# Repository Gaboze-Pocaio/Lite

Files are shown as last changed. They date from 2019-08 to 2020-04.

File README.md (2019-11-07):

# Gaboze Lite Edition
Gaboze Lite is an even more no frills version of the Game Boy Pocket and Raspberry Pi Zero.

## What Did We Do?

* [x] Lakka Only Release *(You Can Still Have RetroPie)*
* [x] TP4056 Module Removed for more efficient Texs Instruments
* [x] 5V Power Rail
* [x] Full USB OTG Support
* [x] New Button Library With Better Actuation
* [x] Two Buttons Only

## Why Did We Do This

Well, we slimmed it down to a two button build (you can always wire more on your own). After market evaluation, and to keep costs lower.

## Preview

| Top  | Bottom |
| ---- | --- |
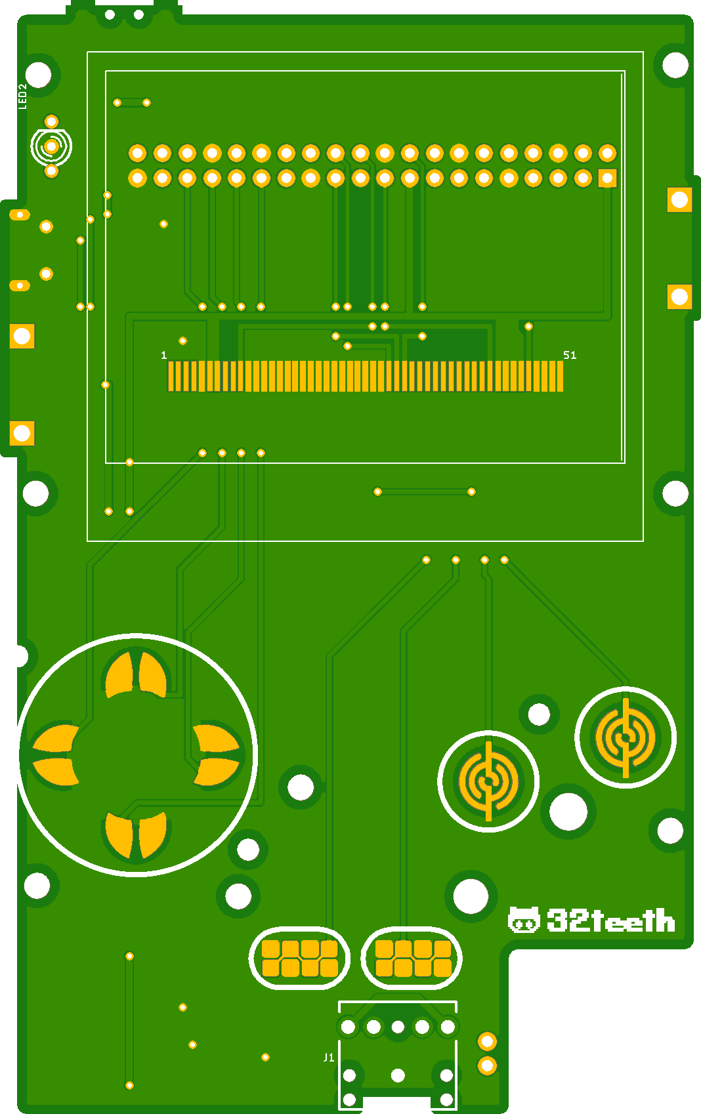
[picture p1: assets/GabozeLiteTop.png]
Top Board
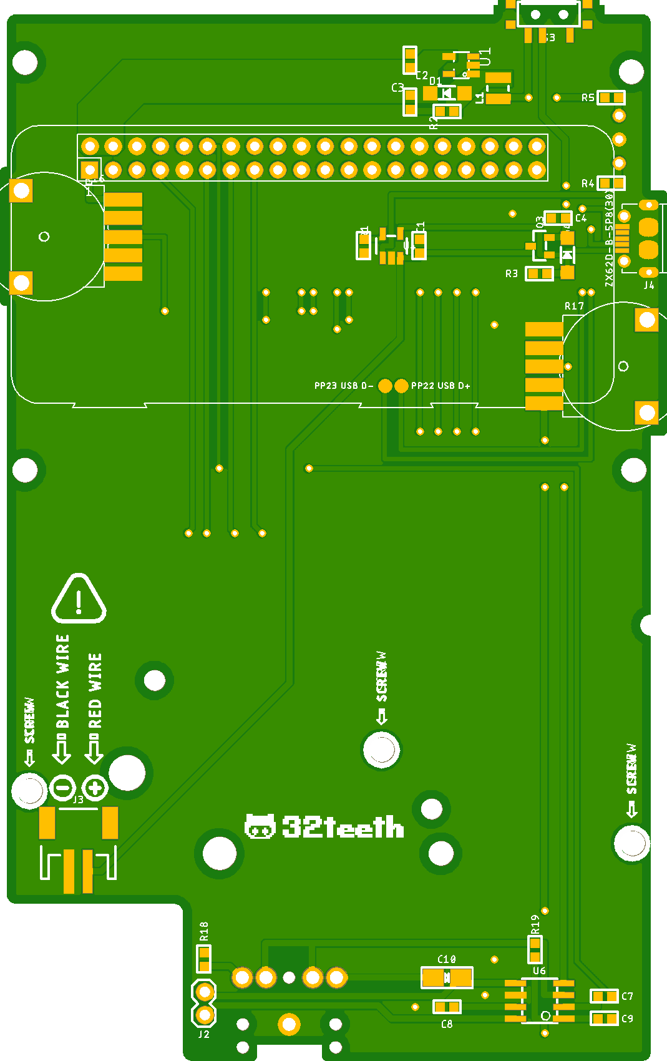
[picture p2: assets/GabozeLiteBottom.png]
Bottom Board
| |  |

## More Soon
> Stay Up To Date

* [x] Be Sure To **Watch** This Repo
* [ ] Help Out By **Starring** This Repo

------
#### Buy Us A Coffee
> It's Not Mandatory, But Much [Appreciated](https://www.paypal.me/32teeth/1.99USD)

Everything we provide is free to use, Feedback is always welcome.

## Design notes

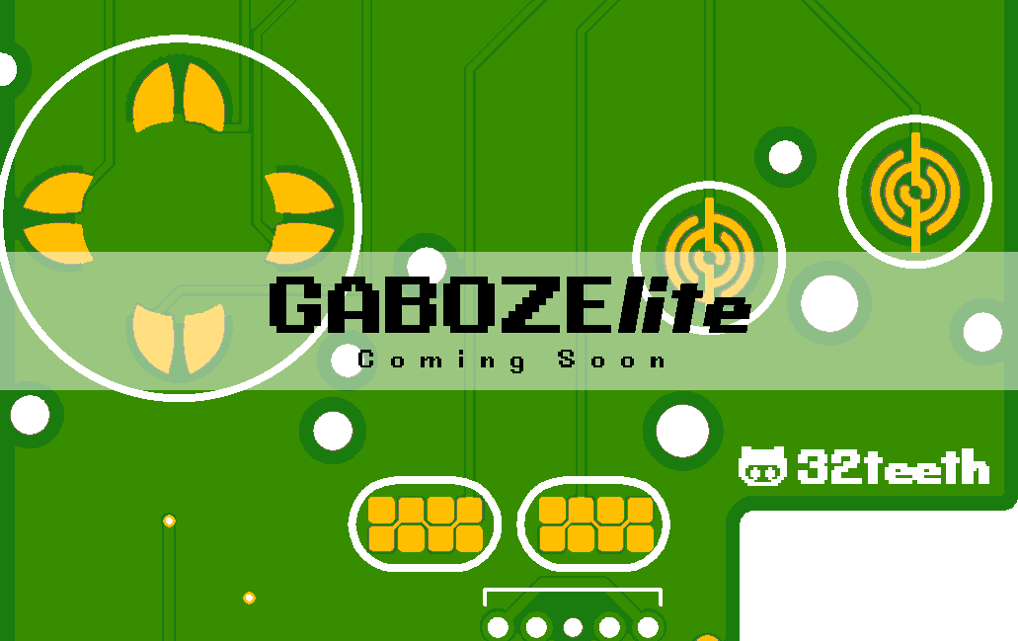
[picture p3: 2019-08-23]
assets/cover.png

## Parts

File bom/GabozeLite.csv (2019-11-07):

Qty | Value | Device | Package | Parts | Description | MPN | NO_BOM | PROD_ID | SF_ID | VALUE
1 | 1.5K | MICROBUILDER_RESISTOR0603MINI | MICROBUILDER_0603-MINI | R5 | Resistors | ERJ-PA3J152V
2 | 100K | MICROBUILDER_RESISTOR0603MINI | MICROBUILDER_0603-MINI | R3, R19 | Resistors | ERJ-PA3J104V
1 | 100uF | CAP_TANTALUMA/3216_WAVE | EIA3216-18/A-W | C10 | Tantalum Capacitors | 6TPH100MAEA
2 | 10uF | MICROBUILDER_CAP_CERAMIC0603MINI | MICROBUILDER_0603-MINI | C1, C4 | Ceramic Capacitors | CL10A106MP8NNNC
1 | 150 Ohm | MICROBUILDER_RESISTOR0603MINI | MICROBUILDER_0603-MINI | R18 | Resistors | ERJ-PA3J151V
2 | 1uF | MICROBUILDER_CAP_CERAMIC0603MINI | MICROBUILDER_0603-MINI | C8, C9 | Ceramic Capacitors | CL10A105KP8NNNC
1 | 220pF | MICROBUILDER_CAP_CERAMIC0603MINI | MICROBUILDER_0603-MINI | C7 | Ceramic Capacitors | CL10C221JB8NNNC
2 | 27k | GBA_VOLUME | GBA_VOLUME | R16, R17
1 | 4.7K | MICROBUILDER_RESISTOR0603MINI | MICROBUILDER_0603-MINI | R1 | Resistors | ERJ-PA3J472V
1 | 470 | MICROBUILDER_RESISTOR0603MINI | MICROBUILDER_0603-MINI | R4 | Resistors | ERJ-PA3J471V
1 | AUDIO_JACK_3.5MM_KIT | AUDIO_JACK_3.5MM_KIT | AUDIO-JACK-KIT | J1 | Audio Jack | SJ1-3525NG-GR |  | CONN-08774 | PRT-08032
1 | Batt Conn | JST_2MM_MALE | JST-2-SMD | J3 | JST 2MM MALE RA CONNECTOR | S2B-PH-SM4-TB(LF)(SN) |  | CONN-11443 | PRT-08612
4 | CONDUCTIVE_BUTTONCONDUCTIVE_BUTTON_DIRECTIONAL_THICK | CONDUCTIVE_BUTTONCONDUCTIVE_BUTTON_DIRECTIONAL_THICK | CONDUCTIVE_BUTTON_DIRECTIONAL_THICK | DOWN, LEFT, RIGHT, UP
2 | CONDUCTIVE_BUTTONCONDUCTIVE_BUTTON_THICK | CONDUCTIVE_BUTTONCONDUCTIVE_BUTTON_THICK | CONDUCTIVE_BUTTON_THICK | A, B
2 | CONDUCTIVE_BUTTON_STARTSELECTCONDUCTIVE_BUTTON_THICK_STARTSELECT | CONDUCTIVE_BUTTON_STARTSELECTCONDUCTIVE_BUTTON_THICK_STARTSELECT | CONDUCTIVE_BUTTON_THICK_STARTSELECT | SELECT, START
1 | DMG3415U-7 | MOSFET-P | SOT23-R | Q3 | P-Channel Mosfet | DMG3415U-7
1 | LED_L-115WEGW-CA | LED_L-115WEGW-CA | LED_DUOLED-A-3MM | LED2 | T-1(3mm) BI-COLOR INDICATOR LAMP | SSL-LX3059IGW
1 | LM4875 | LM4875 | SOIC8 | U6 |  | LM4875M/NOPB
1 | MBR120 | DIODE-SCHOTTKYSOD-123 | SOD-123 | D4 |  | MBR120LSFT1G
1 | MCP73831T-2ACI/OT | MCP73831/2 | SOT23-5@1 | U4 | MCP73831/2 LIPO Charger | MCP73831T-2ACI/OT
1 | RPI-ZERO-USB | RPI-ZERO-USB | RPI-ZERO-TH-USB-POGO | PI1
1 | SPKR | CONN_02 | 1X02 | J2 | Multi connection point. Often used as Generic Header-pin footprint for 0.1 inch spaced/style header connections
1 | SWITCH_SPDT | SWITCH_SPDT | KPS-1290 | S3 | SWCH-10651 | RS-187R05A2-DS MT RT |  | SWCH-10651
1 | TFT-DISPLAY-2.6-51PIN | TFT-DISPLAY-2.6-51PIN | TFT-DISPLAY-2.6-51PIN | U5 | ILI9342 51P 2.6 TFT LCD"
1 | ZX62D-B-5P8(30) | MICRO-USB-SMD(ZX62D-B-5P8(30)) | MICRO-USB5+6P-SMD-0.65-AB | J4 | 320010005 | ZX62D-B-5P8(30) |  |  |  | ZX62D-B-5P8(30)

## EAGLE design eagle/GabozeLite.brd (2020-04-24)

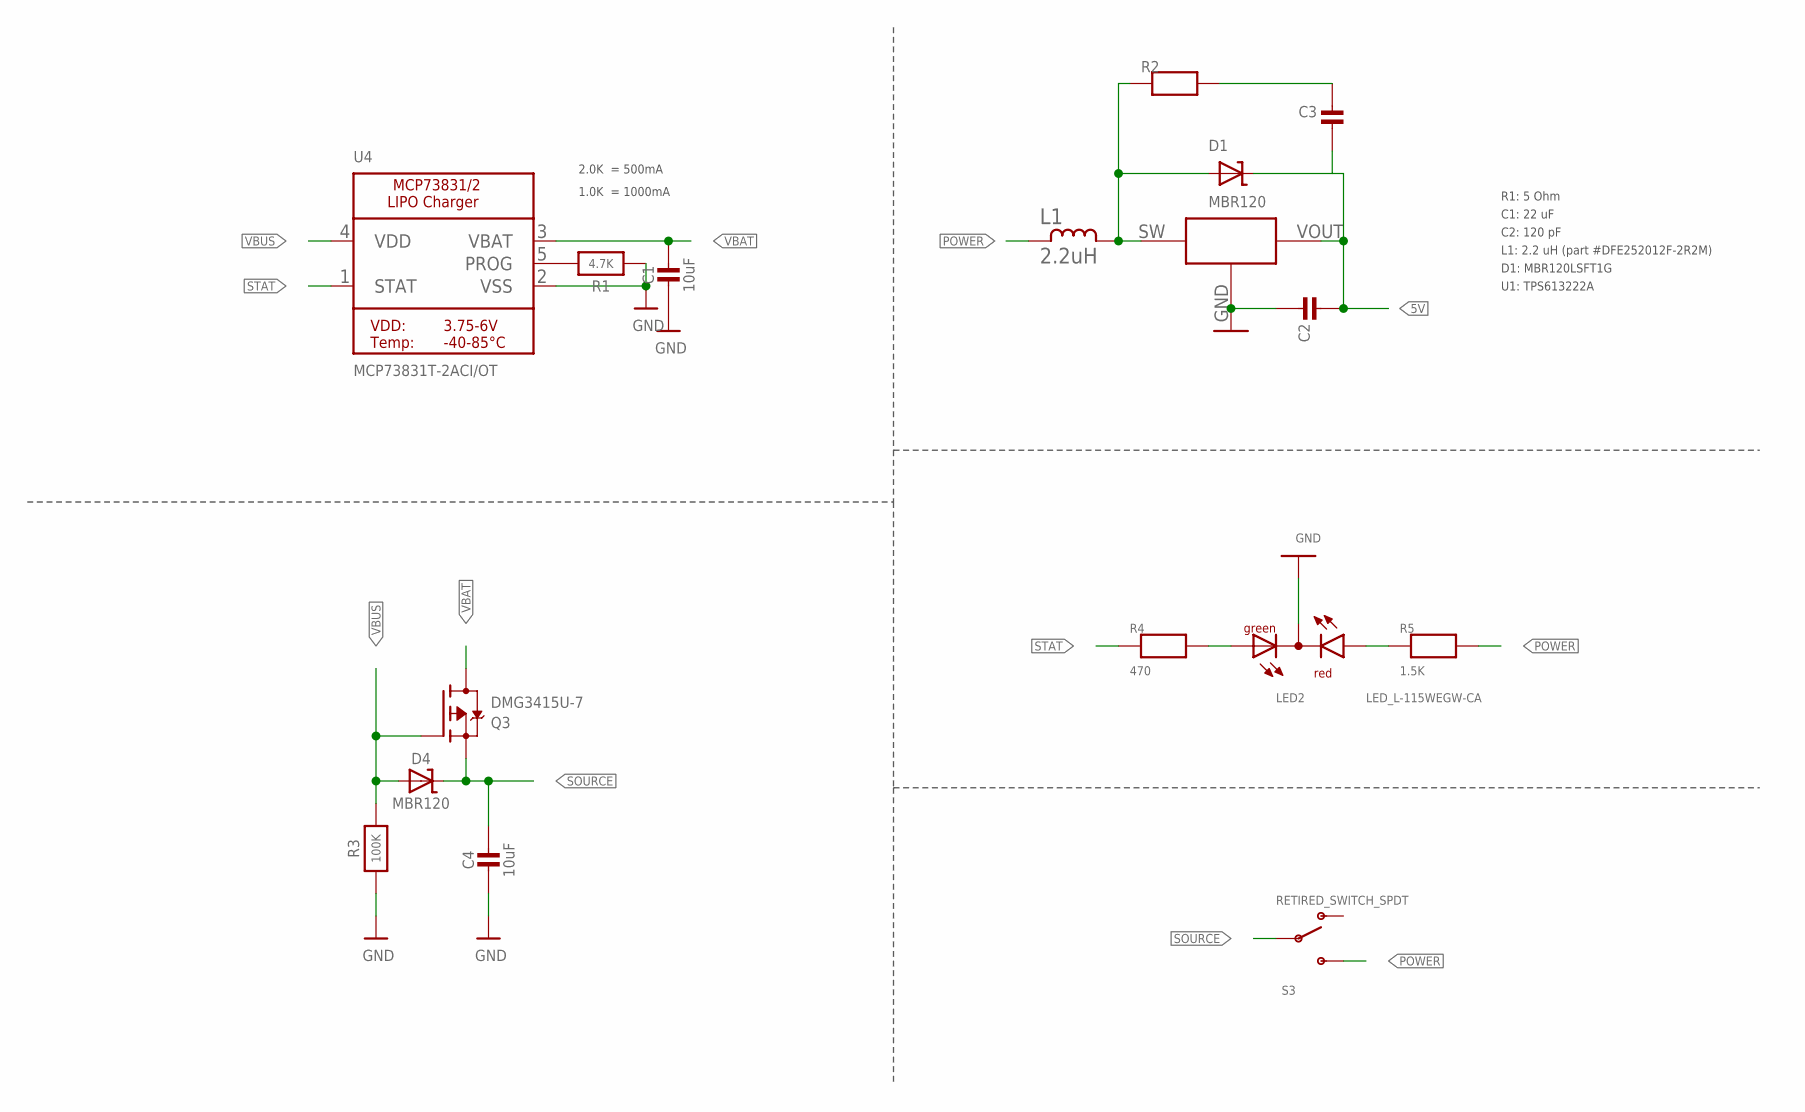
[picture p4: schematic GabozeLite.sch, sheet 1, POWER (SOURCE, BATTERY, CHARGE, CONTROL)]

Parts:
C1, C4: 10uF; 0603-MINI-CAP; MPN CL10A106MP8NNNC
C2: 22uf; 0603-MINI-CAP
C3: 120pf; 0603-MINI-CAP
D1, D4: MBR120; SOD-123; MPN MBR120LSFT1G
L1: 2.2uH; L1008CS
LED2: LED_L-115WEGW-CA; LED_DUOLED-A-3MM; MPN SSL-LX3059IGW
Q3: DMG3415U-7; SOT23-R; MPN DMG3415U-7
R1: 4.7K; 0603-MINI; MPN ERJ-PA3J472V
R2: 5Ohm; 0603-MINI
R3: 100K; 0603-MINI; MPN ERJ-PA3J104V
R4: 470; 0603-MINI; MPN ERJ-PA3J471V
R5: 1.5K; 0603-MINI; MPN ERJ-PA3J152V
S3: RETIRED_SWITCH_SPDT; RETIRED_KPS-1290; MPN RS-187R05A2-DS MT RT
U1: TPS613222A
U4: MCP73831T-2ACI/OT; SOT23-5-1; MPN MCP73831T-2ACI/OT

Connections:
5V: C2.2, C3.2, D1.C, U1.VOUT; also elsewhere on the board
GND: C1.2, C2.1, C4.2, LED2.2 (A), R1.1, R3.1, U1.GND, U4.2 (VSS); also elsewhere on the board
unnamed: D1.A, L1.2, R2.1, U1.SW
unnamed: C3.1, R2.2
POWER: L1.1, R5.2, S3.S
POWER_LED: LED2.3 (CR), R5.1
PROG: R1.2, U4.5 (PROG)
SOURCE: C4.1, D4.C, Q3.2 (S), S3.P
STAT: R4.1, U4.1 (STAT)
STAT_LED: LED2.1 (CG), R4.2
VBAT: C1.1, Q3.3 (D), U4.3 (VBAT); also elsewhere on the board
VBUS: D4.A, Q3.1 (G), R3.2, U4.4 (VDD); also elsewhere on the board

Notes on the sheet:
2.0K = 500mA
1.0K = 1000mA
R1: 5 Ohm C1: 22 uF C2: 120 pF L1: 2.2 uH (part #DFE252012F-2R2M) D1: MBR120LSFT1G U1: TPS613222A

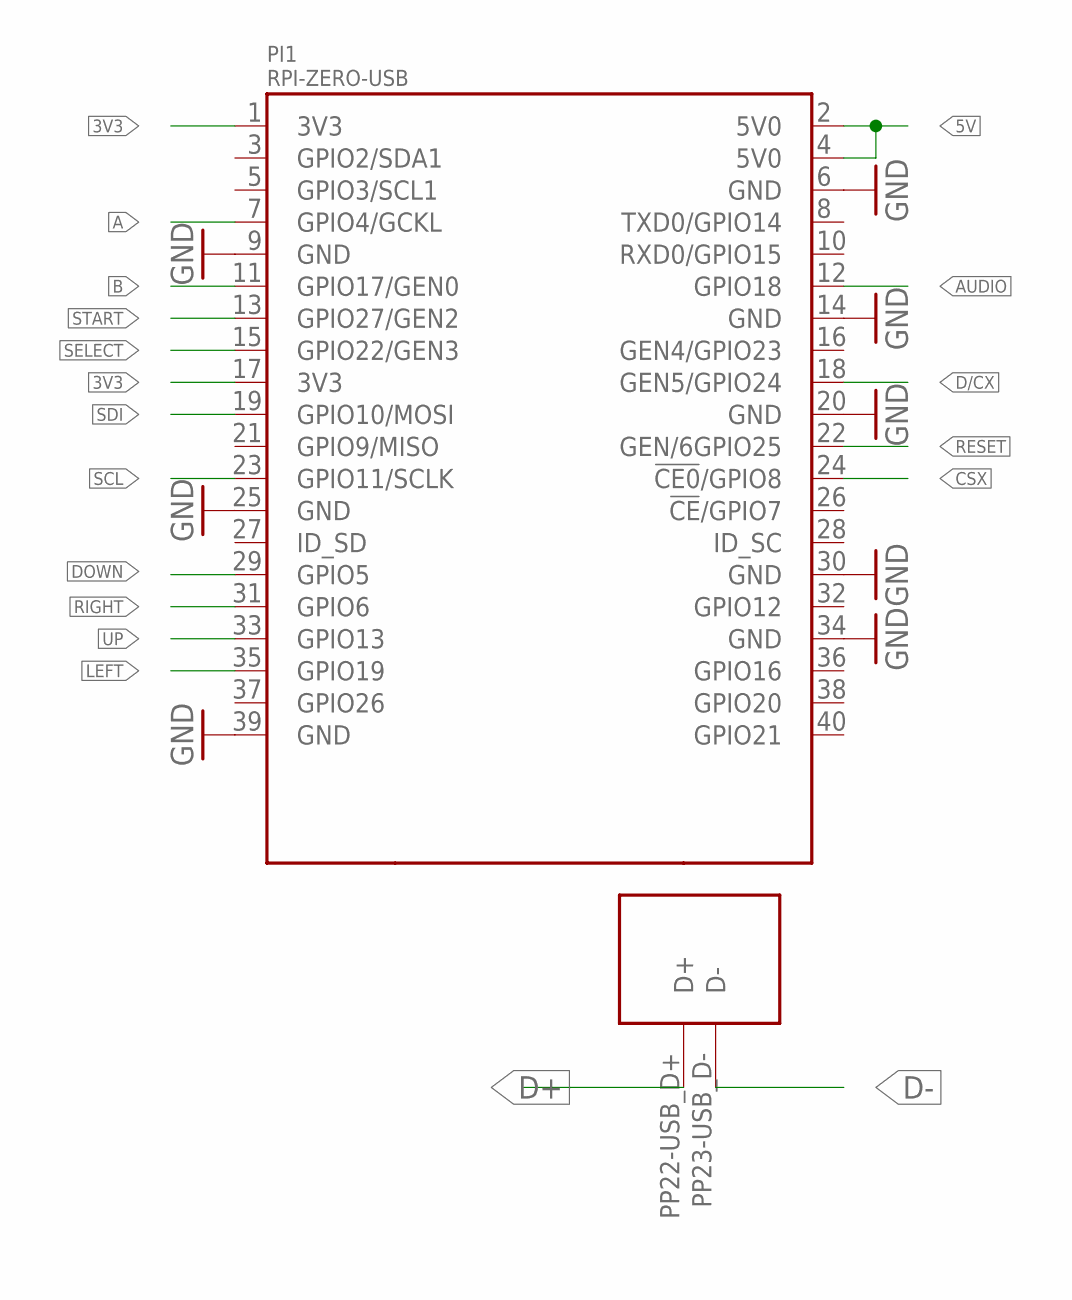
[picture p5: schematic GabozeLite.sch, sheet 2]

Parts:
PI1: RPI-ZERO-USB; RPI-ZERO-TH-USB-POGO

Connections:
3V3: PI1.1 (3V3), PI1.17 (3V3); also elsewhere on the board
5V: PI1.2 (5V0), PI1.4 (5V0); also elsewhere on the board
A: PI1.7 (GPIO4/GCKL); also elsewhere on the board
AUDIO: PI1.12 (GPIO18); also elsewhere on the board
B: PI1.11 (GPIO17/GEN0); also elsewhere on the board
CSX: PI1.24 (!CE0!/GPIO8); also elsewhere on the board
D+: PI1.PP22-USB_D+ (D+); also elsewhere on the board
D-: PI1.PP23-USB_D- (D-); also elsewhere on the board
D/CX: PI1.18 (GEN5/GPIO24); also elsewhere on the board
DOWN: PI1.29 (GPIO5); also elsewhere on the board
GND: PI1.6 (GND), PI1.9 (GND), PI1.14 (GND), PI1.20 (GND), PI1.25 (GND), PI1.30 (GND), PI1.34 (GND), PI1.39 (GND); also elsewhere on the board
LEFT: PI1.35 (GPIO19); also elsewhere on the board
RESET: PI1.22 (GEN/6GPIO25); also elsewhere on the board
RIGHT: PI1.31 (GPIO6); also elsewhere on the board
SCL: PI1.23 (GPIO11/SCLK); also elsewhere on the board
SDI: PI1.19 (GPIO10/MOSI); also elsewhere on the board
SELECT: PI1.15 (GPIO22/GEN3); also elsewhere on the board
START: PI1.13 (GPIO27/GEN2); also elsewhere on the board
UP: PI1.33 (GPIO13); also elsewhere on the board

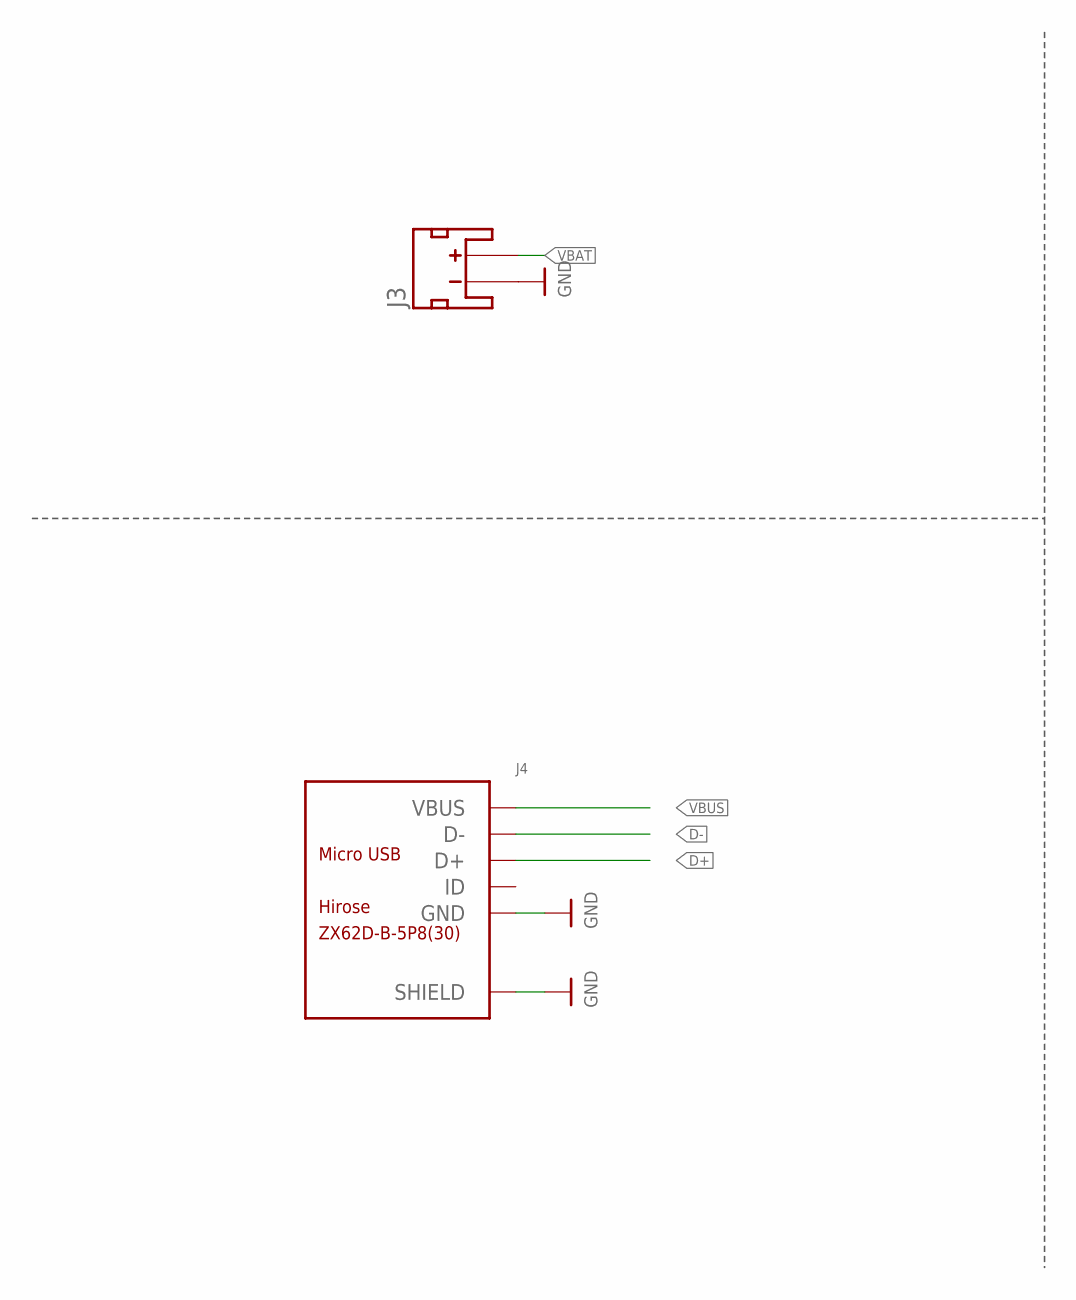
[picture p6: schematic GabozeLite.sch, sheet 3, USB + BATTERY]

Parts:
J3: Batt Conn; JST-2-SMD; MPN S2B-PH-SM4-TB(LF)(SN)
J4: ZX62D-B-5P8(30); MICRO-USB5+6P-SMD-0.65-AB

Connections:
D+: J4.3 (D+); also elsewhere on the board
D-: J4.2 (D-); also elsewhere on the board
GND: J3.1 (-), J4.5 (GND), J4.P1 (SHIELD), J4.P2 (SHIELD), J4.P3 (SHIELD), J4.P4 (SHIELD), J4.P5 (SHIELD), J4.P6 (SHIELD); also elsewhere on the board
VBAT: J3.2 (+); also elsewhere on the board
VBUS: J4.1 (VBUS); also elsewhere on the board

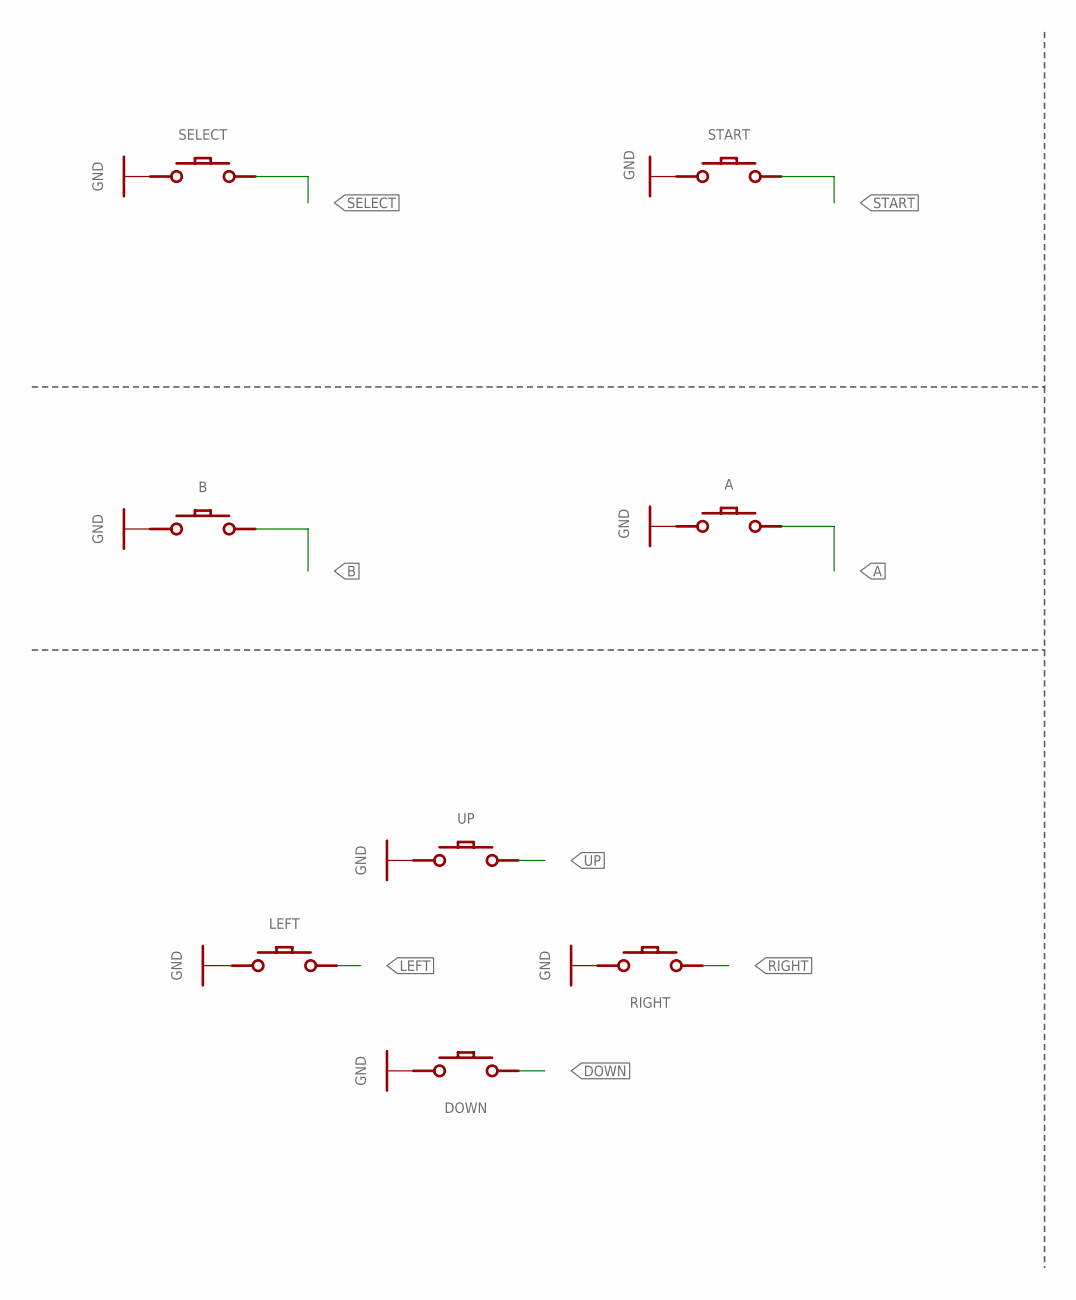
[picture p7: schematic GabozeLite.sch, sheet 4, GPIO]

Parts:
A: CONDUCTIVE_BUTTONCONDUCTIVE_BUTTON_THICK; CONDUCTIVE_BUTTON_THICK
B: CONDUCTIVE_BUTTONCONDUCTIVE_BUTTON_THICK; CONDUCTIVE_BUTTON_THICK
DOWN: CONDUCTIVE_BUTTONCONDUCTIVE_BUTTON_DIRECTIONAL_TH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; CONDUCTIVE_BUTTON_DIRECTIONAL_THICK
LEFT: CONDUCTIVE_BUTTONCONDUCTIVE_BUTTON_DIRECTIONAL_TH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; CONDUCTIVE_BUTTON_DIRECTIONAL_THICK
RIGHT: CONDUCTIVE_BUTTONCONDUCTIVE_BUTTON_DIRECTIONAL_TH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; CONDUCTIVE_BUTTON_DIRECTIONAL_THICK
SELECT: CONDUCTIVE_BUTTON_STARTSELECTCONDUCTIVE_BUTTON_TH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; CONDUCTIVE_BUTTON_THICK_STARTSELECT
START: CONDUCTIVE_BUTTON_STARTSELECTCONDUCTIVE_BUTTON_TH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; CONDUCTIVE_BUTTON_THICK_STARTSELECT
UP: CONDUCTIVE_BUTTONCONDUCTIVE_BUTTON_DIRECTIONAL_TH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; CONDUCTIVE_BUTTON_DIRECTIONAL_THICK

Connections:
A: A.P$ACTIVE; also elsewhere on the board
B: B.P$ACTIVE; also elsewhere on the board
DOWN: DOWN.P$ACTIVE; also elsewhere on the board
GND: A.P$GND, B.P$GND, DOWN.P$GND, LEFT.P$GND, RIGHT.P$GND, SELECT.P$GND, SELECT.P$GND1 (P$GND), SELECT.P$GND2 (P$GND), SELECT.P$GND3 (P$GND), START.P$GND, START.P$GND1 (P$GND), START.P$GND2 (P$GND), START.P$GND3 (P$GND), UP.P$GND; also elsewhere on the board
LEFT: LEFT.P$ACTIVE; also elsewhere on the board
RIGHT: RIGHT.P$ACTIVE; also elsewhere on the board
SELECT: SELECT.P$ACTIVE, SELECT.P$ACTIVE1 (P$ACTIVE), SELECT.P$ACTIVE2 (P$ACTIVE), SELECT.P$ACTIVE3 (P$ACTIVE), SELECT.P$ACTIVE4 (P$ACTIVE), SELECT.P$ACTIVE5 (P$ACTIVE), SELECT.P$ACTIVE6 (P$ACTIVE); also elsewhere on the board
START: START.P$ACTIVE, START.P$ACTIVE1 (P$ACTIVE), START.P$ACTIVE2 (P$ACTIVE), START.P$ACTIVE3 (P$ACTIVE), START.P$ACTIVE4 (P$ACTIVE), START.P$ACTIVE5 (P$ACTIVE), START.P$ACTIVE6 (P$ACTIVE); also elsewhere on the board
UP: UP.P$ACTIVE; also elsewhere on the board

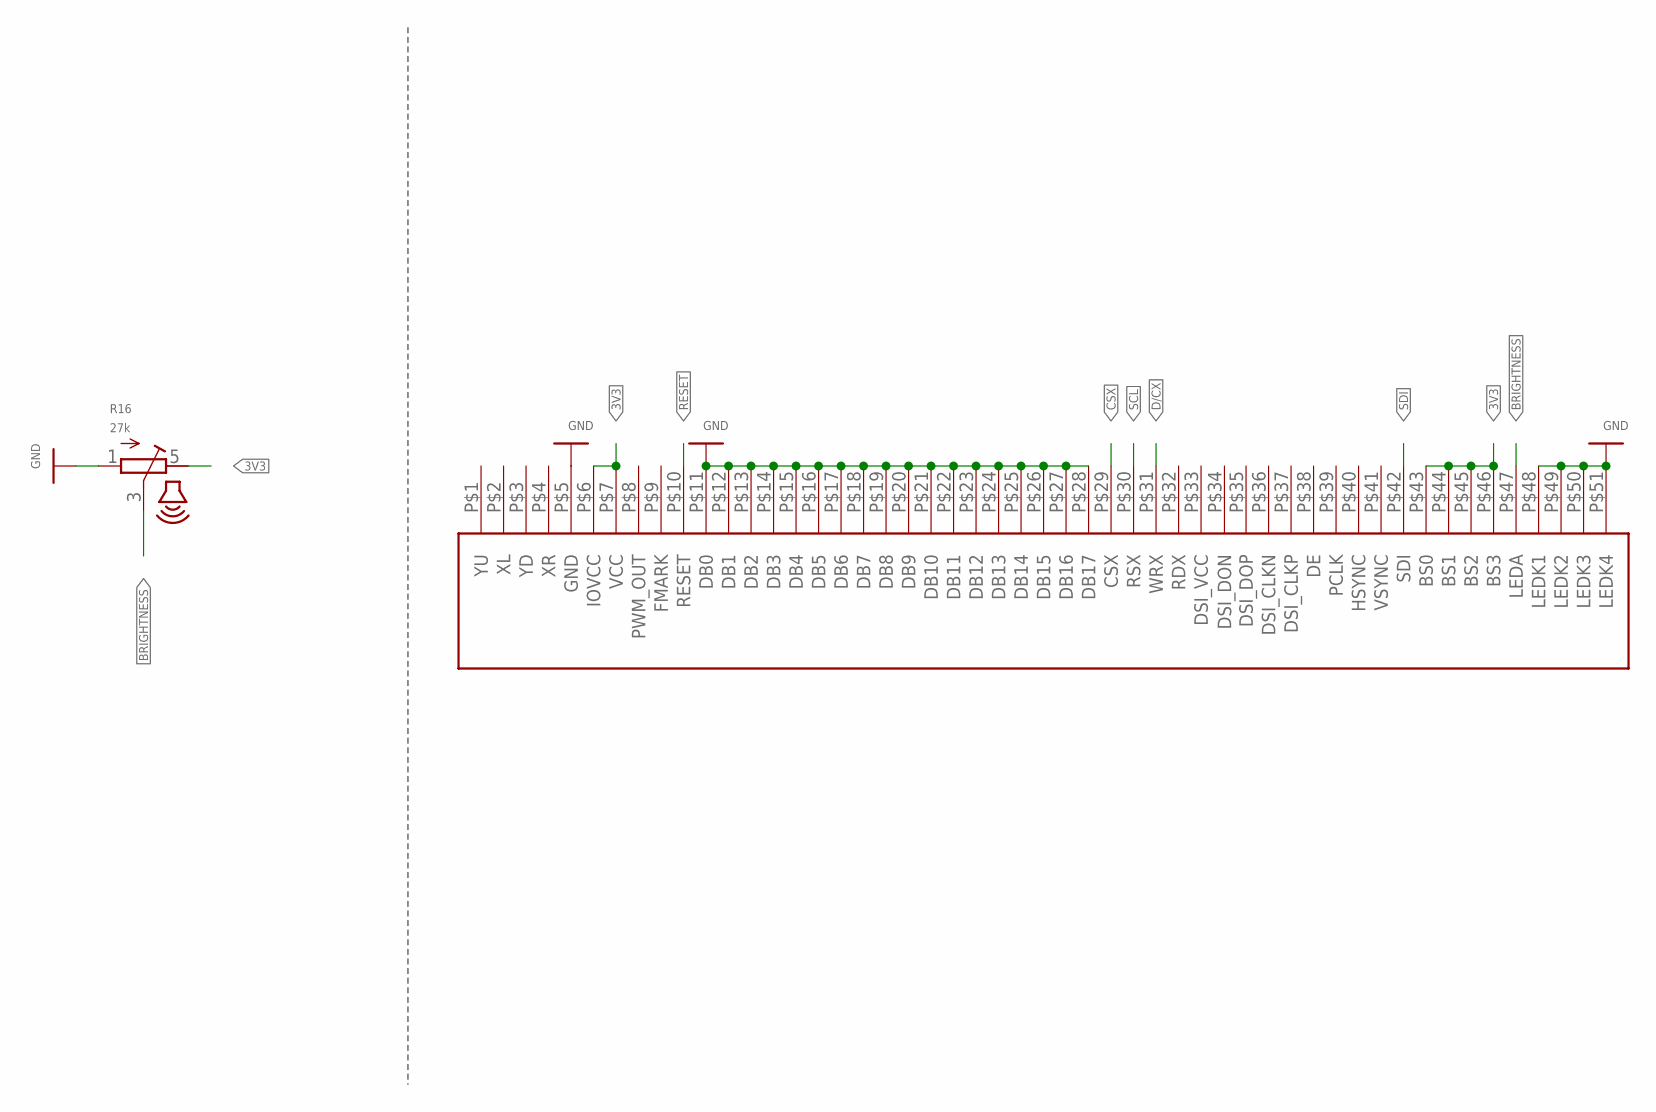
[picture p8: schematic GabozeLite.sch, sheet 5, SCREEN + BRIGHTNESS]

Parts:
R16: 27k; THUMBWHEEL
U5: ILI9342-2.6"

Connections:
3V3: R16.5 (E), U5.P$6 (IOVCC), U5.P$7 (VCC), U5.P$43 (BS0), U5.P$44 (BS1), U5.P$45 (BS2), U5.P$46 (BS3); also elsewhere on the board
BRIGHTNESS: R16.3 (S), U5.P$47 (LEDA)
CSX: U5.P$29 (CSX); also elsewhere on the board
D/CX: U5.P$31 (WRX); also elsewhere on the board
GND: R16.1 (A), U5.P$5 (GND), U5.P$11 (DB0), U5.P$12 (DB1), U5.P$13 (DB2), U5.P$14 (DB3), U5.P$15 (DB4), U5.P$16 (DB5), U5.P$17 (DB6), U5.P$18 (DB7), U5.P$19 (DB8), U5.P$20 (DB9), U5.P$21 (DB10), U5.P$22 (DB11), U5.P$23 (DB12), U5.P$24 (DB13), U5.P$25 (DB14), U5.P$26 (DB15), U5.P$27 (DB16), U5.P$28 (DB17), U5.P$48 (LEDK1), U5.P$49 (LEDK2), U5.P$50 (LEDK3), U5.P$51 (LEDK4); also elsewhere on the board
RESET: U5.P$10 (RESET); also elsewhere on the board
SCL: U5.P$30 (RSX); also elsewhere on the board
SDI: U5.P$42 (SDI); also elsewhere on the board

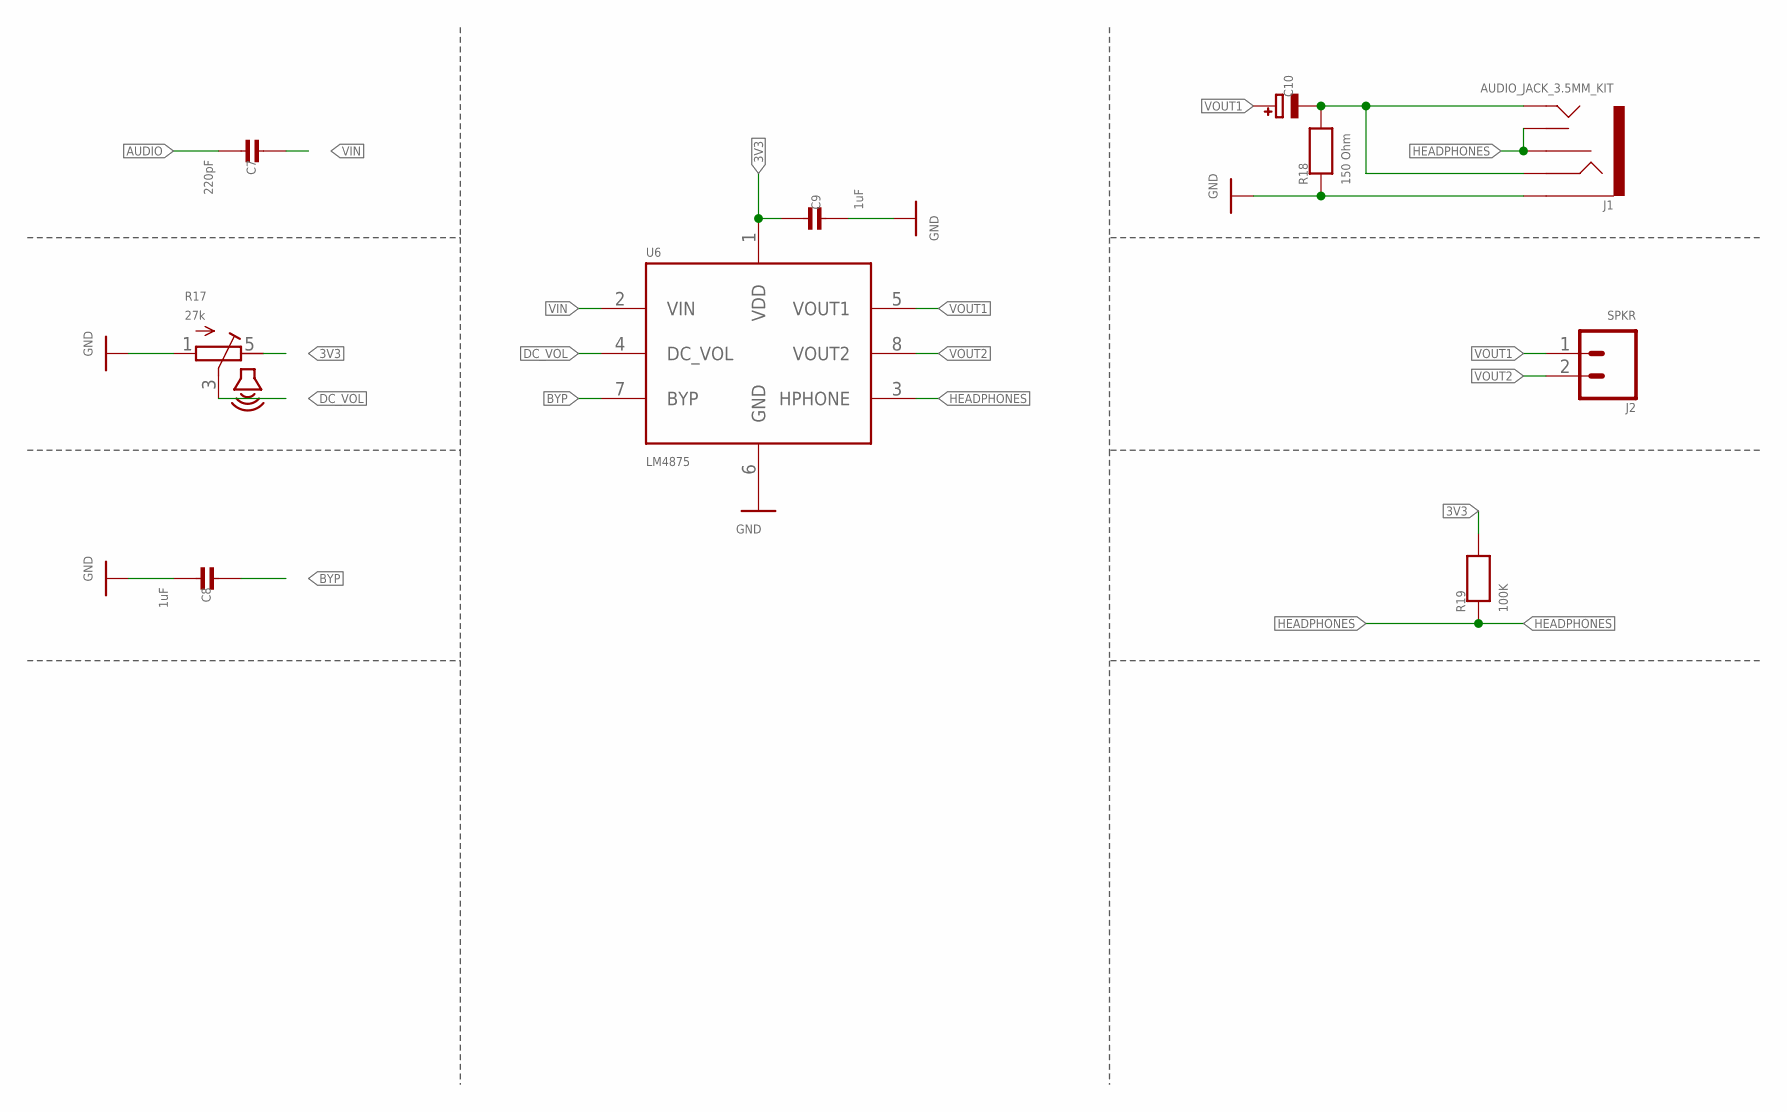
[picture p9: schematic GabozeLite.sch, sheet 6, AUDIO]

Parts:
C7: 220pF; 0603-MINI-CAP; MPN CL10C221JB8NNNC
C8, C9: 1uF; 0603-MINI-CAP; MPN CL10A105KP8NNNC
C10: 100uF; EIA3216-18/A-W; MPN 6TPH100MAEA
J1: AUDIO_JACK_3.5MM_KIT; AUDIO-JACK-KIT; MPN SJ1-3525NG-GR
J2: SPKR; 1X02
R17: 27k; THUMBWHEEL
R18: 150 Ohm; 0603-MINI; MPN ERJ-PA3J151V
R19: 100K; 0603-MINI; MPN ERJ-PA3J104V
U6: LM4875; SOIC8; MPN LM4875M/NOPB

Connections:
3V3: C9.1, R17.5 (E), R19.2, U6.1 (VDD); also elsewhere on the board
AUDIO: C7.2; also elsewhere on the board
BYP: C8.1, U6.7 (BYP)
DC_VOL: R17.3 (S), U6.4 (DC_VOL)
GND: C8.2, C9.2, J1.SLEEVE, R17.1 (A), R18.1, U6.6 (GND); also elsewhere on the board
HEADPHONES: J1.RSH, J1.TSH, R19.1, U6.3 (HPHONE)
VIN: C7.1, U6.2 (VIN)
VIN1: C10.-, J1.RING, J1.TIP, R18.2
VOUT1: C10.+, J2.1, U6.5 (VOUT1)
VOUT2: J2.2, U6.8 (VOUT2)

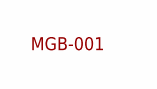
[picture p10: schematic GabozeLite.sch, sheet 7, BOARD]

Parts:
U$1: MGB-001

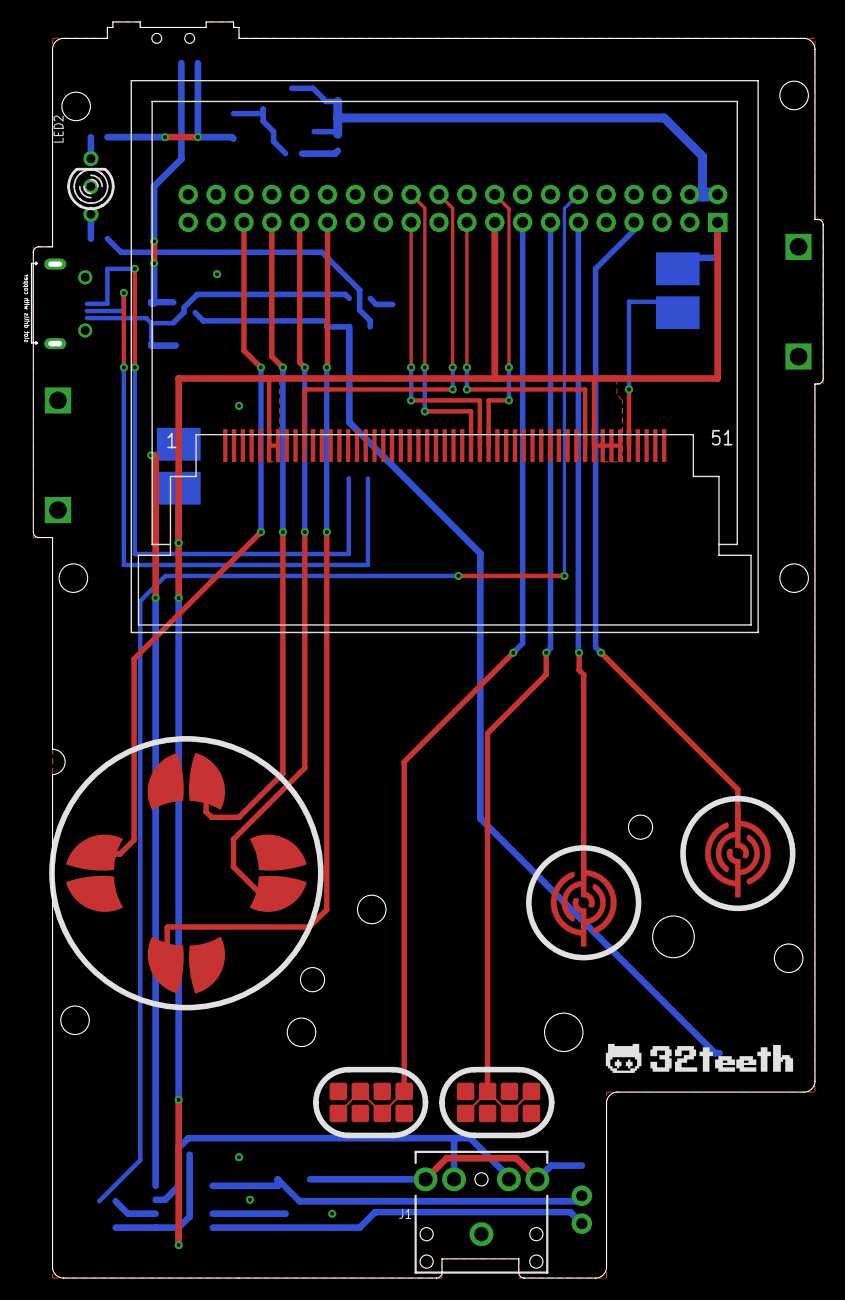
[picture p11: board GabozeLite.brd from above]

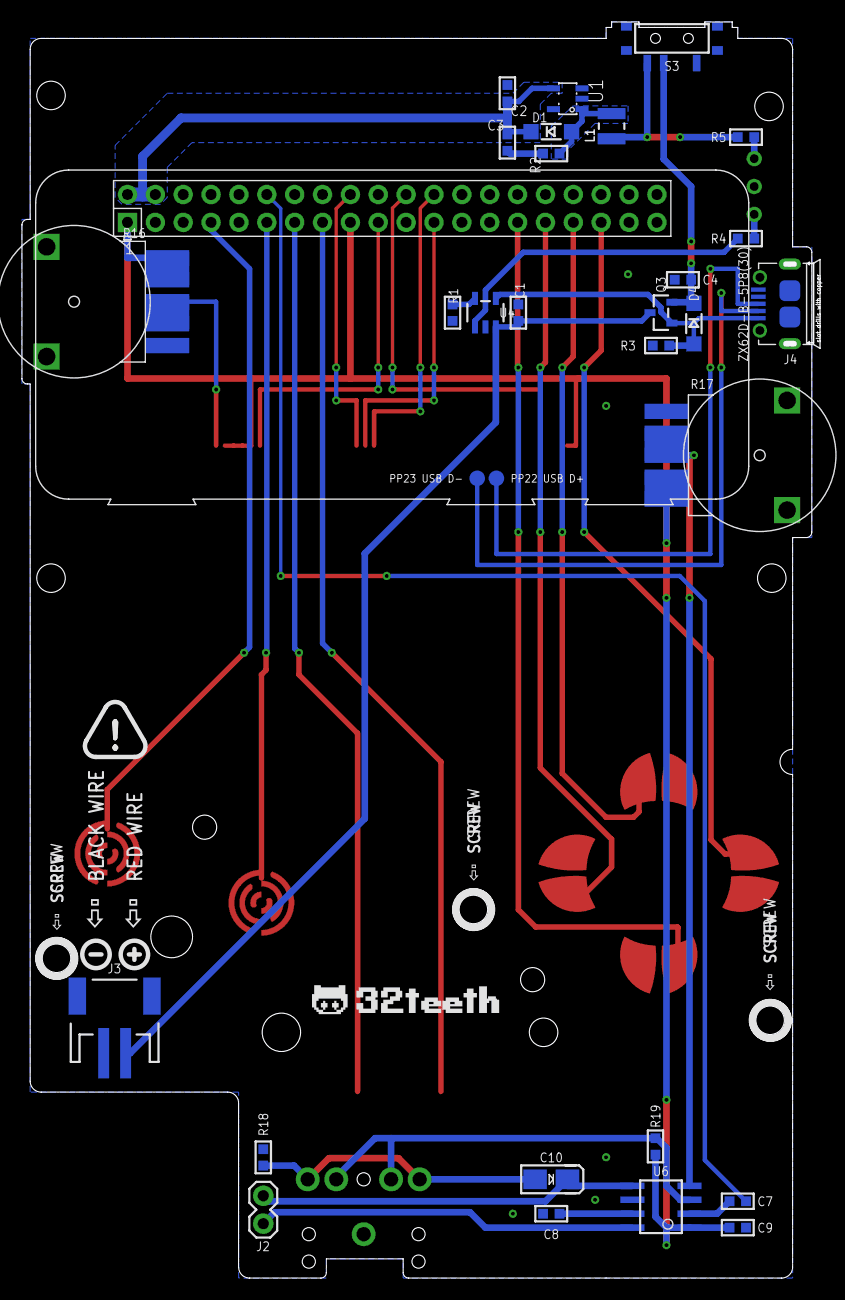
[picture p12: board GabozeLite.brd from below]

Board: 2 copper layers, 72.0 x 114.5 mm, 41 parts (29 on the bottom side), 37 nets.

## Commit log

2019-11-07 Thu 7 Nov 2019 06:29:39 EST - added Gerber and BOM
    [GabozeLite.csv]
2020-04-24 Fri 24 Apr 2020 18:03:15 EDT - add source .brd and .sch files for public consumption
    [GabozeLite.brd, GabozeLite.sch]

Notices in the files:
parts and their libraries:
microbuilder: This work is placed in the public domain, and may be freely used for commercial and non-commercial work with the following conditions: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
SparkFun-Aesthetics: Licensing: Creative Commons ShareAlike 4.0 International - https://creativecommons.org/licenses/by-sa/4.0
